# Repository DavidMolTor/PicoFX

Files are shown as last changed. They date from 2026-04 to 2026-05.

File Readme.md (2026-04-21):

# PICO FX

A simple stereo guitar effects platform using an RP Pico 2 development board.

## Introduction

This module is designed to be used as a development platform for guitar effects running on the RP2350 architecture.

The module contains a CS4272 codec with stereo inputs and outputs. It also includes a set of clean buffers to match the guitar and other effects in the chain.

All the power regulation is done through LDO regulators that prioritize low ripple in exchange for worse efficiency.

It is designed to work with 9V intput voltage. It also has a set of headers for it to be able to interface with a control board in the future.

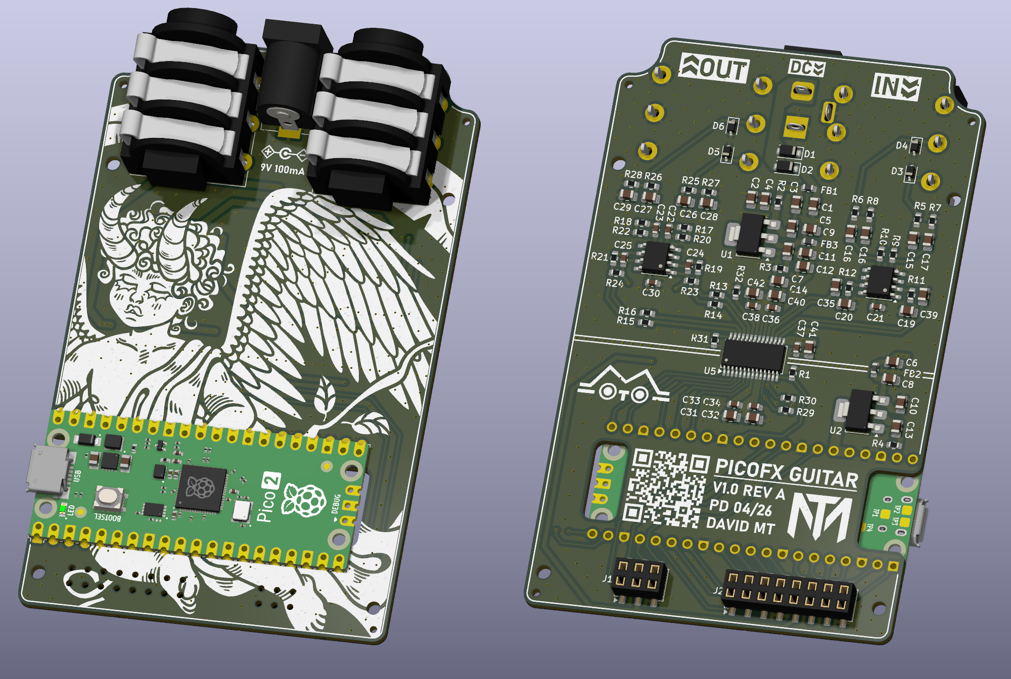
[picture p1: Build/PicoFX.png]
PICO FX


## Features

 - Clear separation between digital and analog sections.

 - Steareo input and output.

 - Clean voltage delivery.

 - Flexible interface for controls.

 - Easy future development.

 - Afforable BOM.

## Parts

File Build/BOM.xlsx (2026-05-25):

Reference | Qty | Value | Manufacturer Part | JLCPCB Part
C1,C2,C3,C4,C5,C6,C7,C8,C9,C10,C11,C12,C13,C14,C17,C18,C26,C27,C42 | 19 | 10u | CL21A106KAYNNNE | C15850
C15,C16,C19,C20,C28,C29,C35,C39 | 8 | 2.2n | CL21C222JBFNNNE | C28260
C21,C30,C33,C34,C36,C37,C38 | 7 | 100n | CC0603KRX7R9BB104 | C14663
C22,C23,C24,C25 | 4 | 330p | CL10C331JB8NNNC | C1664
C31,C32,C40,C41 | 4 | 1u | CL21B105KBFNNNE | C28323
D1 | 1 | SMF10CA | SMF10CA | C19077505
D2 | 1 | DSK24 | DSK24 | C22466352
D3,D4,D5,D6 | 4 | H15VSD3B | H15VSD3B | C20615814
FB1,FB2,FB3 | 3 | 850 | SDCL1608C68NJTDF | C13415
R1,R27,R28,R31,R32 | 5 | 47K | 0603WAF4702T5E | C25819
R2,R5,R6,R25,R26 | 5 | 100 | 0603WAF1000T5E | C22775
R3,R4 | 2 | 1 | 0603WAF100KT5E | C22936
R7,R8,R9,R10 | 4 | 1M | 0603WAF1004T5E | C22935
R11,R12 | 2 | 1K | 0603WAF1001T5E | C21190
R13,R14,R15,R16 | 4 | 15K | 0603WAF1502T5E | C22809
R17,R18,R23,R24 | 4 | 11K | 0603WAF1102T5E | C25950
R19,R20,R21,R22 | 4 | 820 | 0603WAF8200T5E | C23253
R29,R30 | 2 | 2.2K | 0603WAF2201T5E | C4190
U1 | 1 | AMS1117-5.0 | AMS1117-5.0 | C6187
U2 | 1 | AMS1117-3.3 | AMS1117-3.3 | C6186
U3,U4 | 2 | MCP6002-xSN | MCP6002T-I/SN | C7377
U5 | 1 | CS4272 | CS4272-CZZR | C2151111

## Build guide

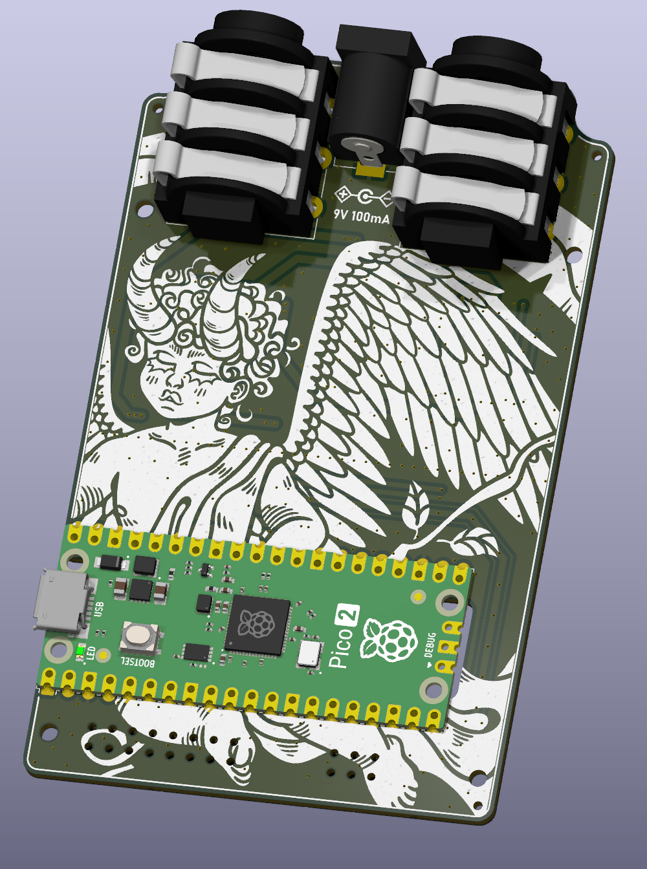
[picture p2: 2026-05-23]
Build/Front.png

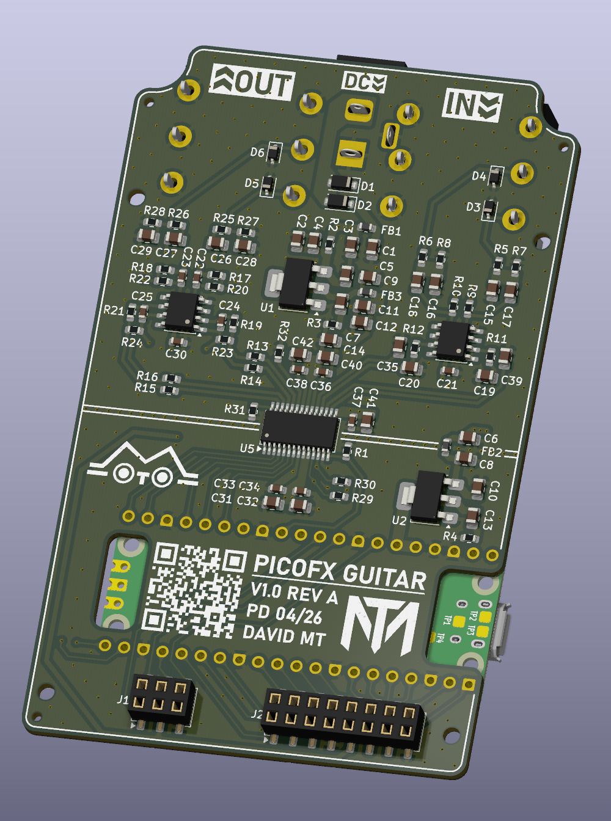
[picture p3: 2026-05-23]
Build/Back.png

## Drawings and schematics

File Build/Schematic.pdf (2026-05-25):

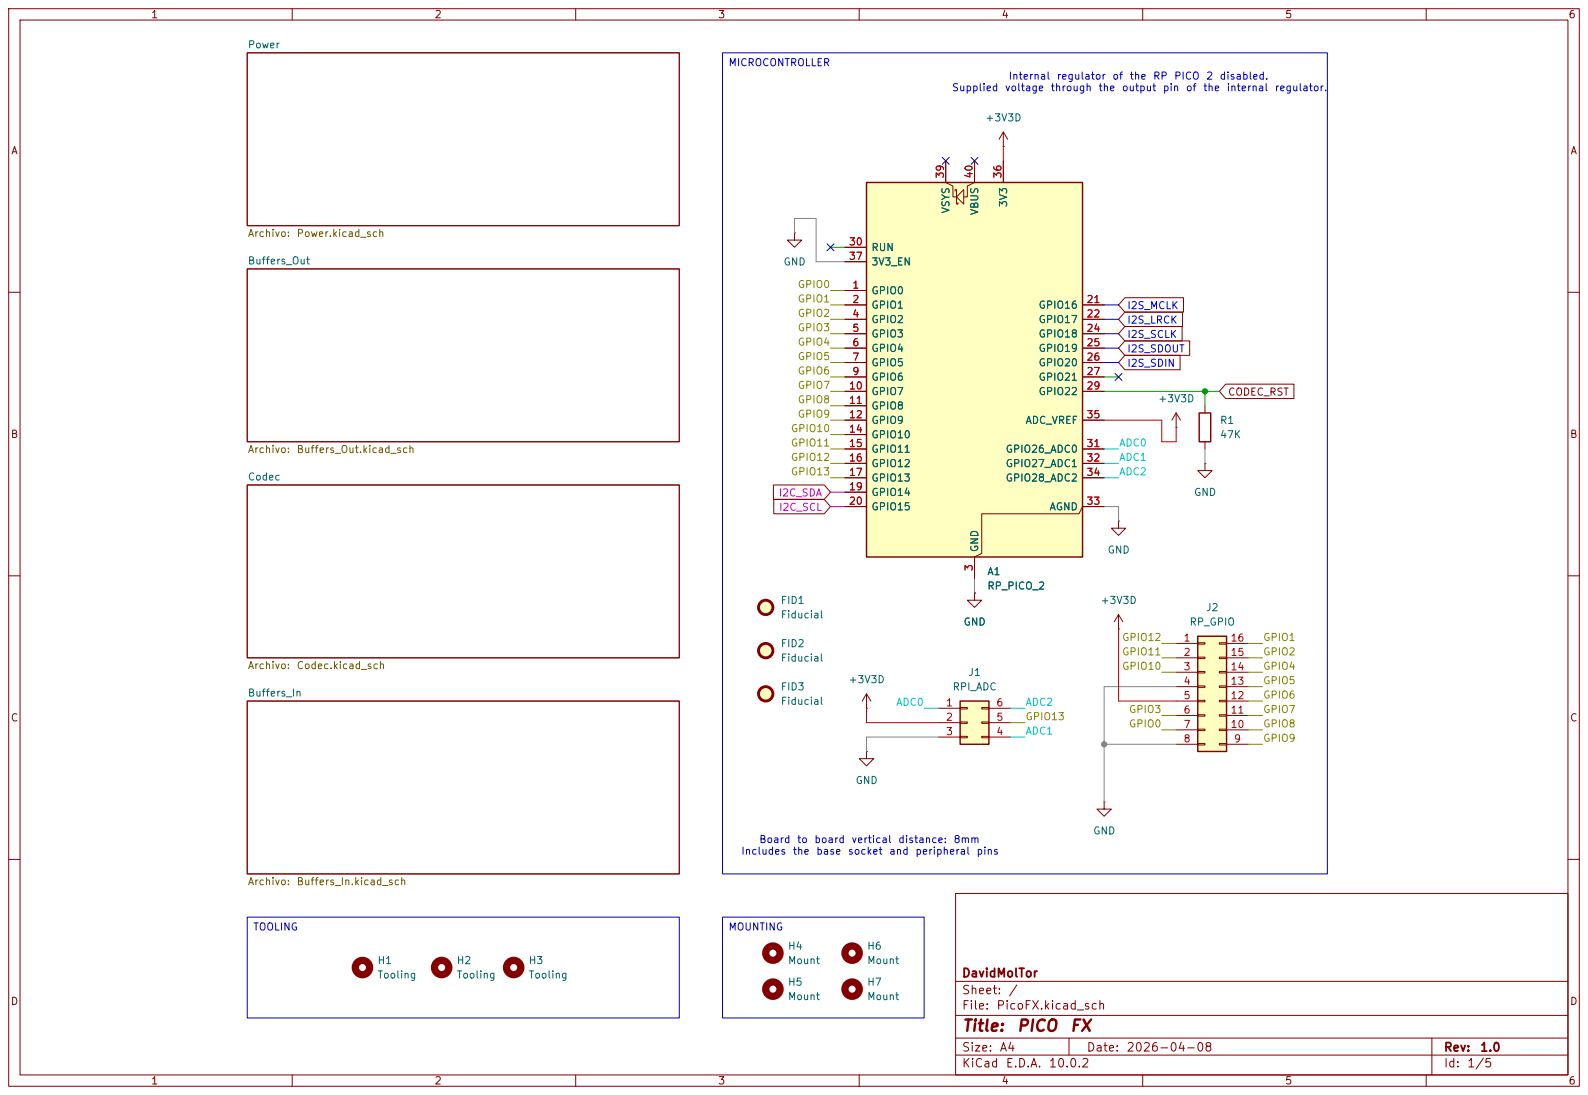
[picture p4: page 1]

Internal regulator of the RP PICO 2 disabled. Supplied voltage through the output pin of the internal regulator.

Board to board vertical distance: 8mm

Size: A4 | Rev: 1.0
KiCad E.D.A. 10.0.2 | Id: 1/5

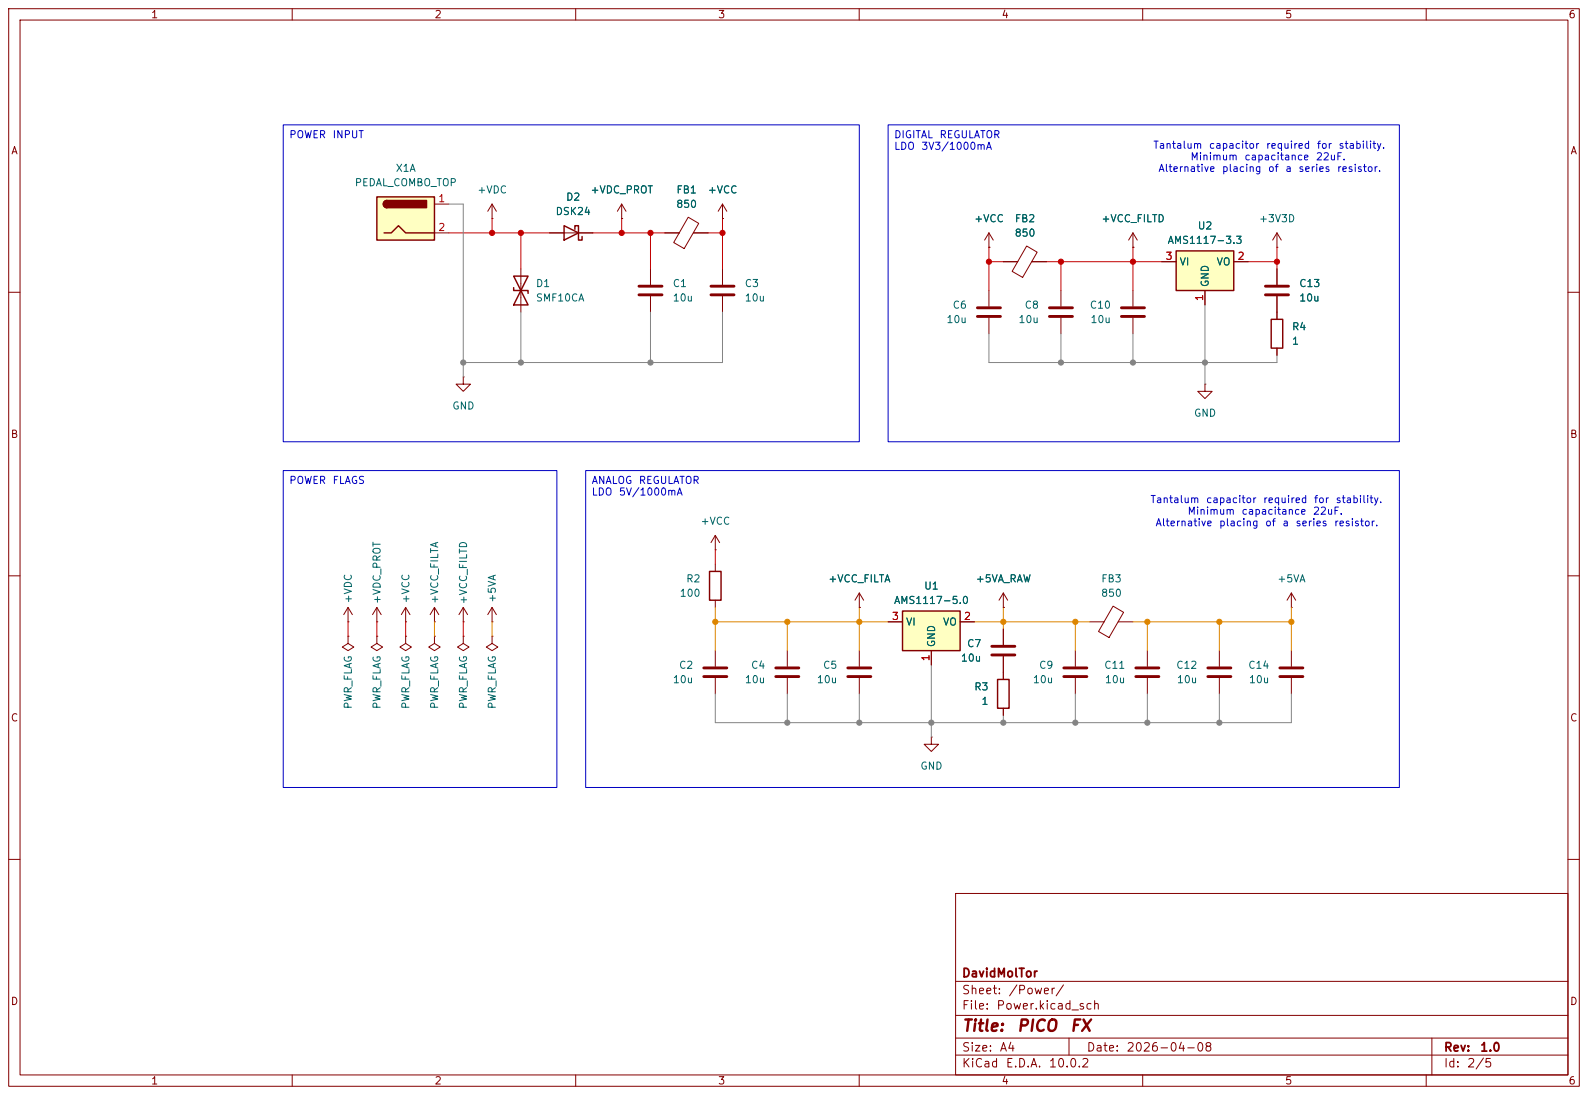
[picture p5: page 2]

Tantalum capacitor required for stability. Minimum capacitance 22uF. Alternative placing of a series resistor. Tantalum capacitor required for stability. Minimum capacitance 22uF. Alternative placing of a series resistor. +VCC FB2

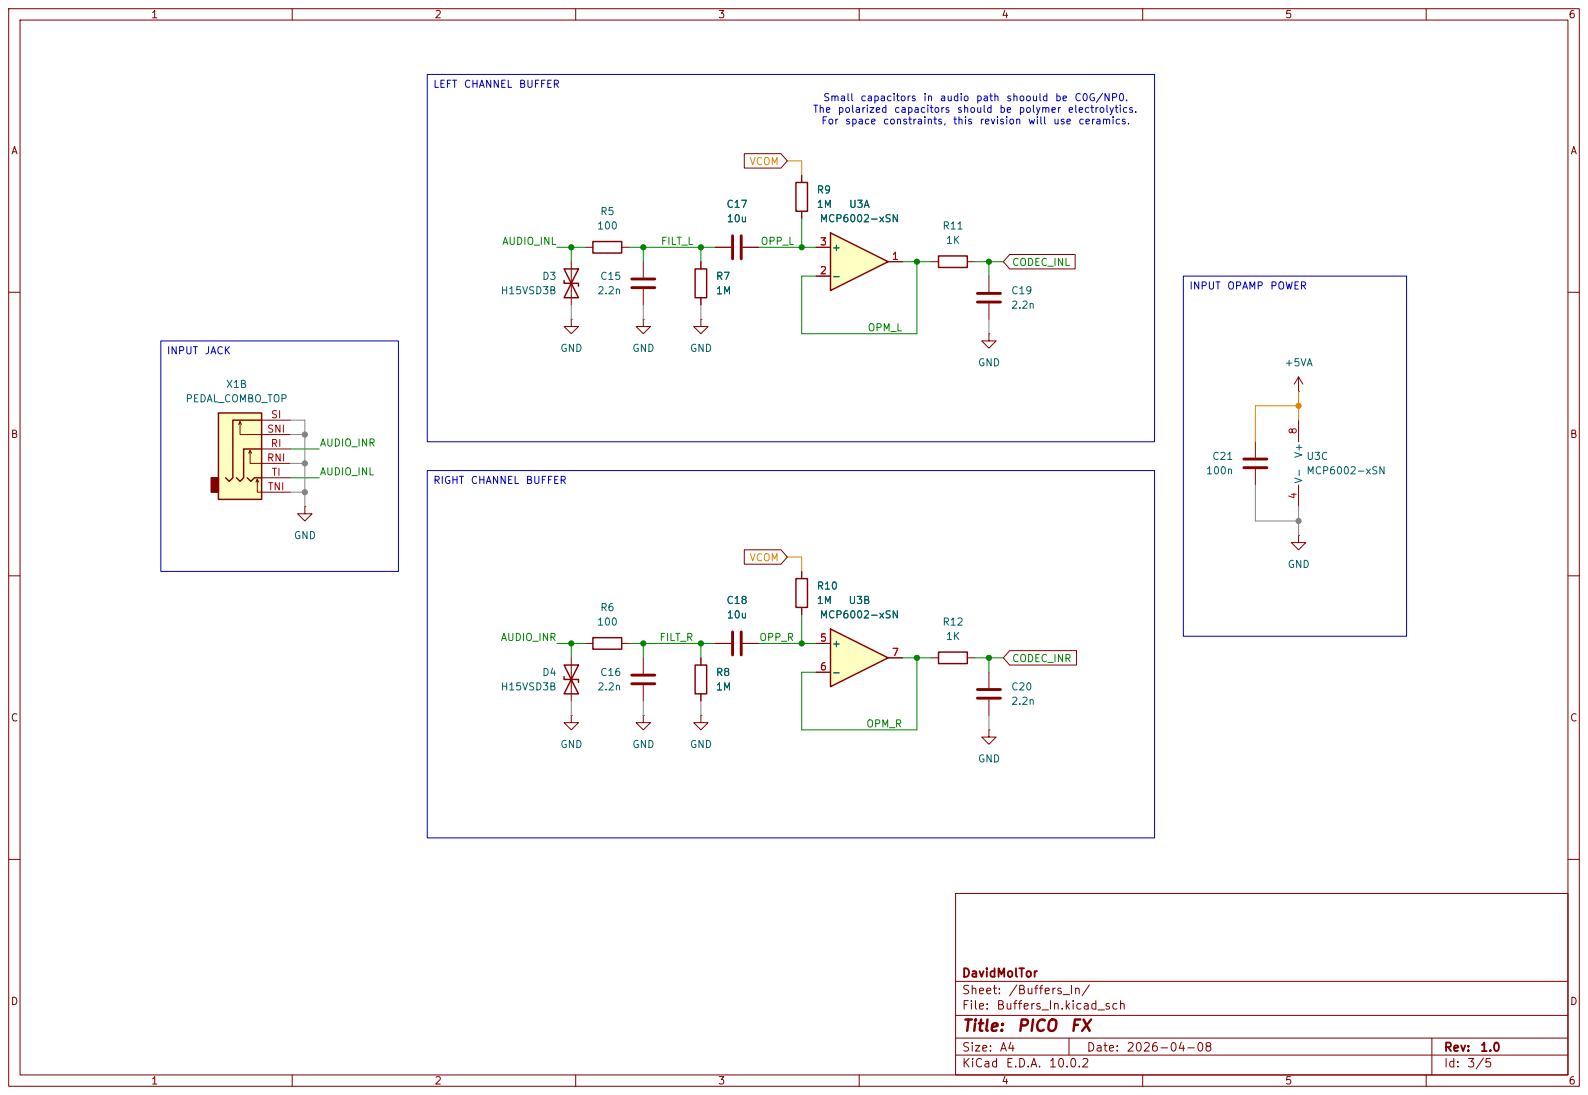
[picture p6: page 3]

Small capacitors in audio path shoould be C0G/NP0. The polarized capacitors should be polymer electrolytics. For space constraints, this revision will use ceramics. U3A MCP6002-xSN

RI RNI SI SNI TI TNI X1B

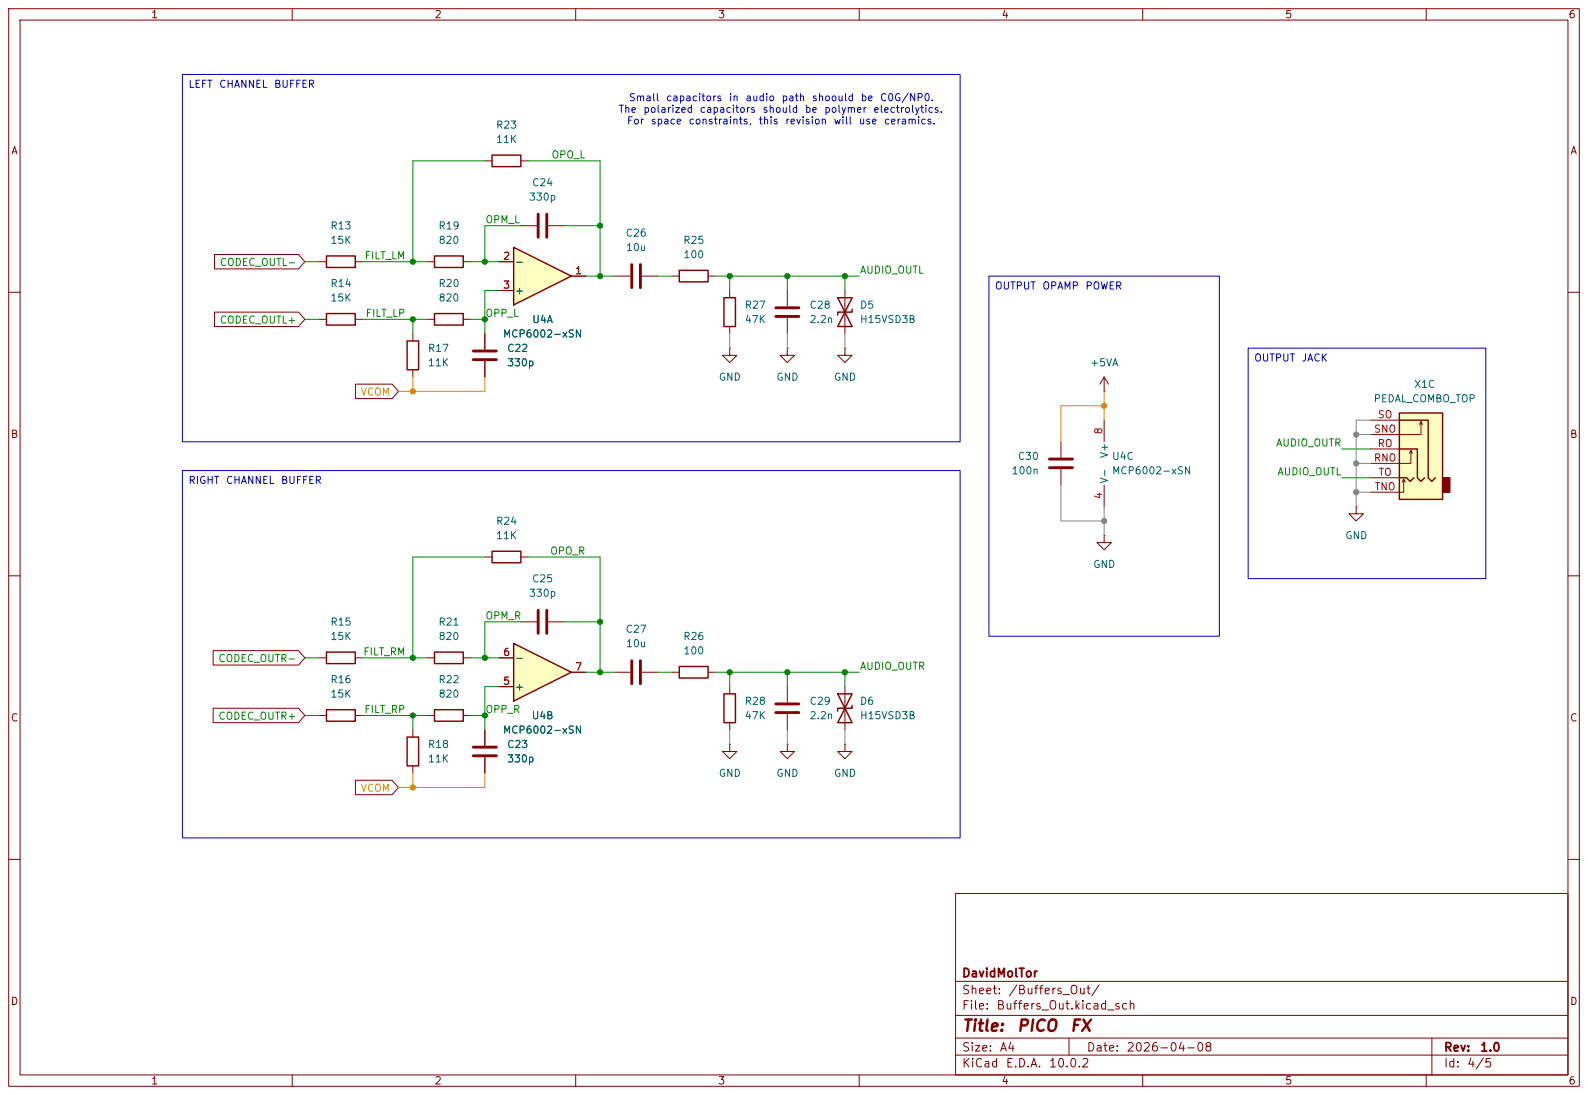
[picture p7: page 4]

Small capacitors in audio path shoould be C0G/NP0. The polarized capacitors should be polymer electrolytics. For space constraints, this revision will use ceramics. C22

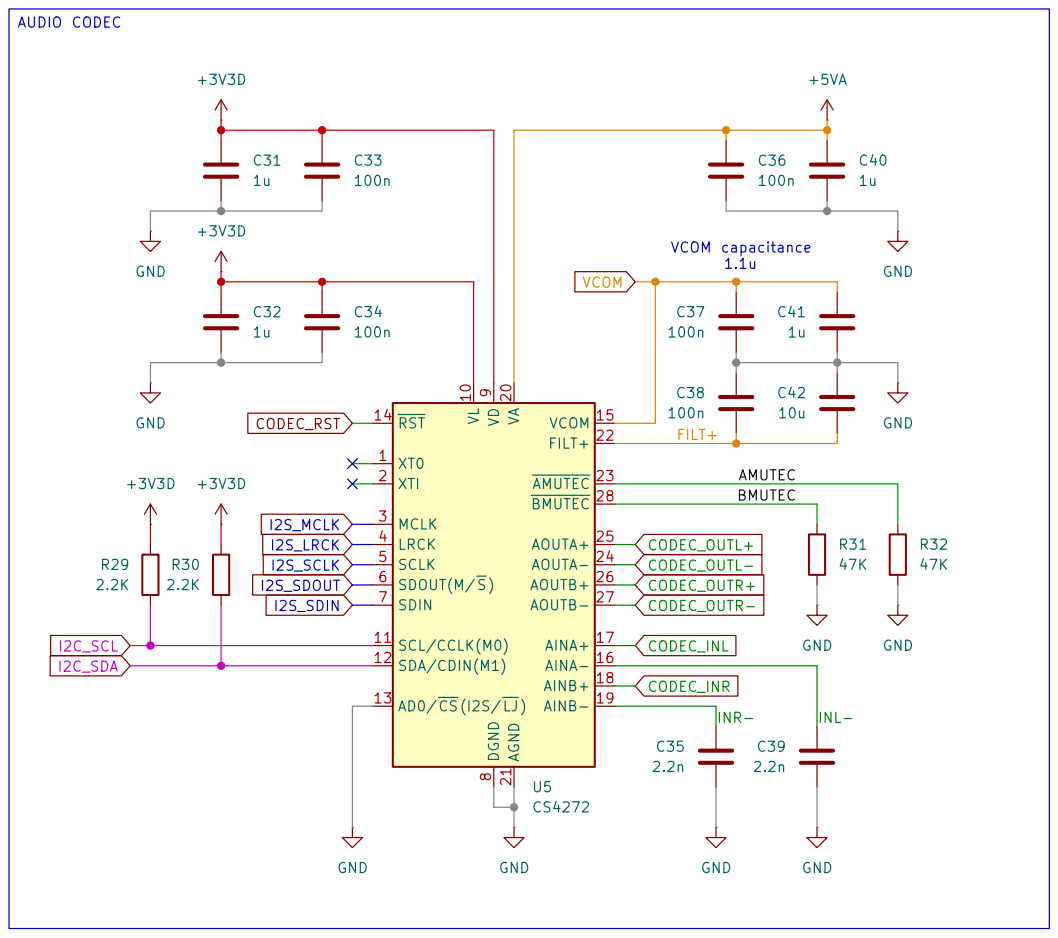
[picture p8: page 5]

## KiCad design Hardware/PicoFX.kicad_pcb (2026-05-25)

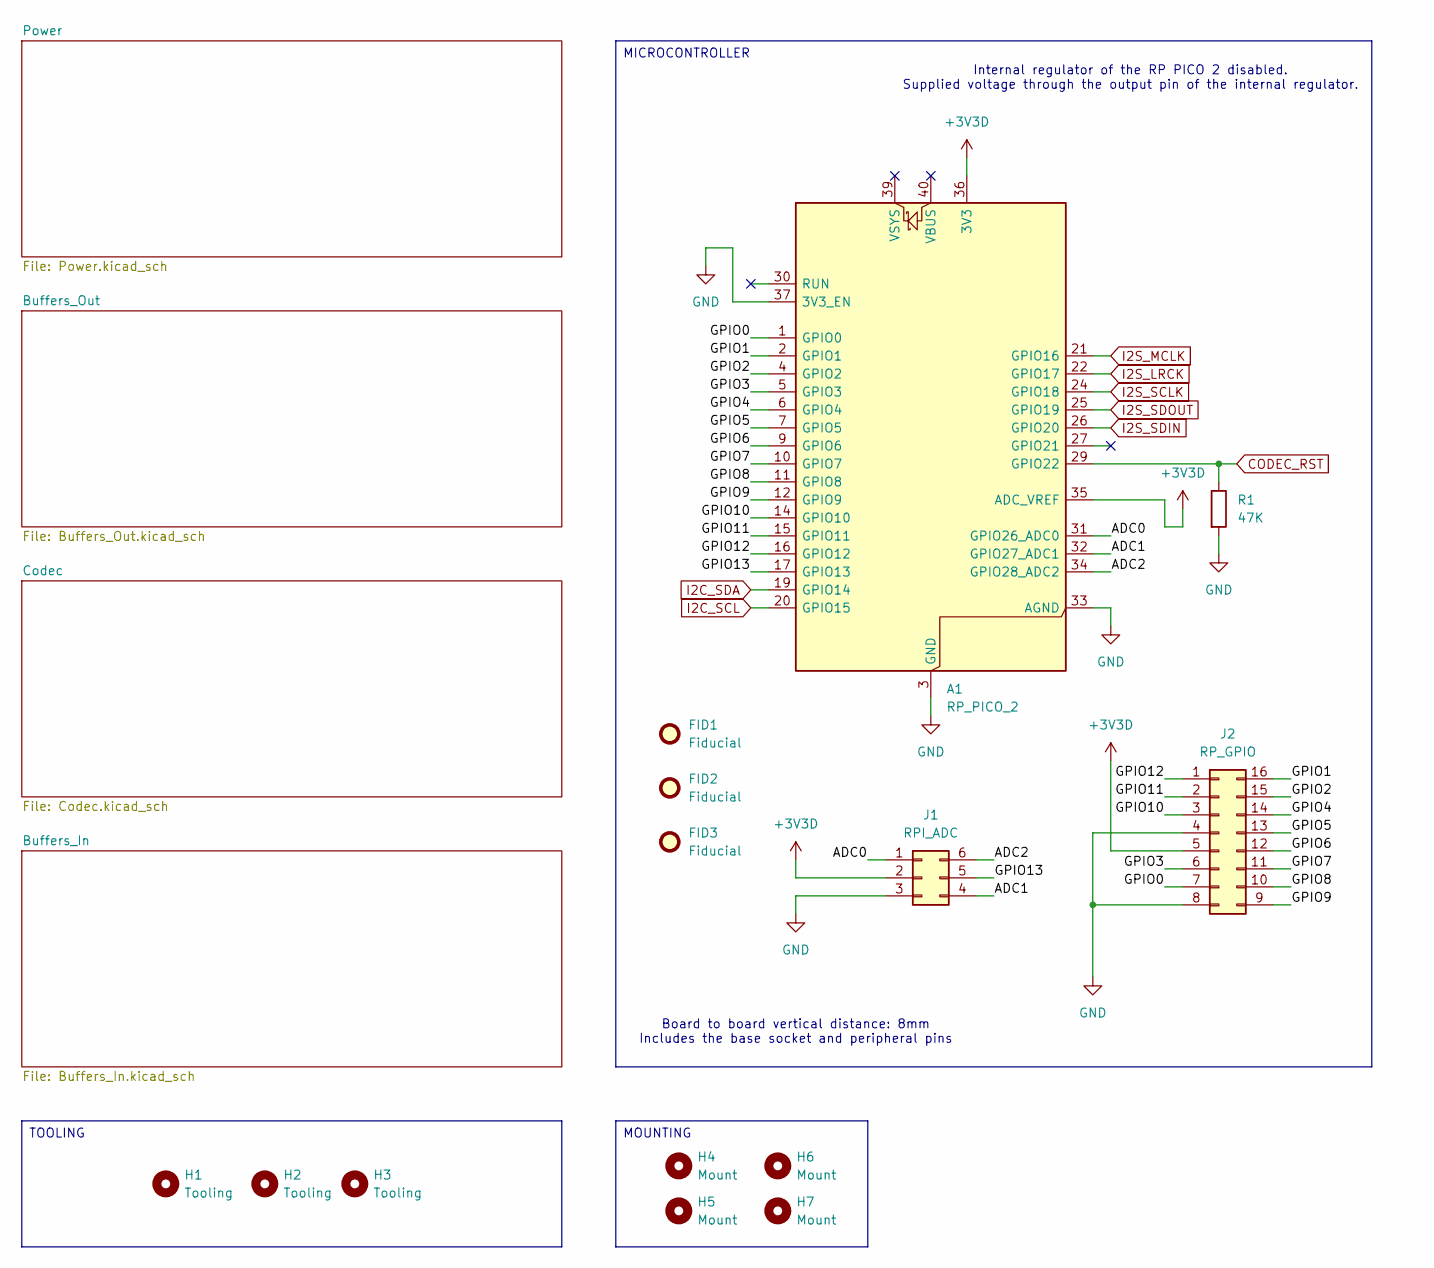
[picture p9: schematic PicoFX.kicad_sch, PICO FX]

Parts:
A1: RP_PICO_2; RP_PICO_2_SMD; Manufacturer Part Pico 2; JLCPCB Part C41407547
FID1, FID2, FID3: Fiducial; Fiducial_0.75mm_Mask1.5mm
H1, H2, H3: Tooling; ToolingHole_1.152mm
H4, H5, H6, H7: Mount; MountingHole_2.2mm_M2
J1: RPI_ADC; HEADER_THROUGH_2x03_P2.54mm; Manufacturer Part HC-PM254-5.0H-2x3PS-02A; JLCPCB Part C42163131
J2: RP_GPIO; HEADER_THROUGH_2x08_P2.54mm; Manufacturer Part HC-PM254-5.0H-2x8PS; JLCPCB Part C42163136
R1: 47K; R_0603_1608Metric; Manufacturer Part 0603WAF4702T5E; JLCPCB Part C25819

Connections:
+3V3D: A1.35 (ADC_VREF), A1.36 (3V3), J1.2, J2.5; also elsewhere on the board
/ADC0: A1.31 (GPIO26_ADC0), J1.1
/ADC1: A1.32 (GPIO27_ADC1), J1.4
/ADC2: A1.34 (GPIO28_ADC2), J1.6
/GPIO0: A1.1 (GPIO0), J2.7
/GPIO1: A1.2 (GPIO1), J2.16
/GPIO2: A1.4 (GPIO2), J2.15
/GPIO3: A1.5 (GPIO3), J2.6
/GPIO4: A1.6 (GPIO4), J2.14
/GPIO5: A1.7 (GPIO5), J2.13
/GPIO6: A1.9 (GPIO6), J2.12
/GPIO7: A1.10 (GPIO7), J2.11
/GPIO8: A1.11 (GPIO8), J2.10
/GPIO9: A1.12 (GPIO9), J2.9
/GPIO10: A1.14 (GPIO10), J2.3
/GPIO11: A1.15 (GPIO11), J2.2
/GPIO12: A1.16 (GPIO12), J2.1
/GPIO13: A1.17 (GPIO13), J1.5
CODEC_RST: A1.29 (GPIO22), R1.1; also elsewhere on the board
GND: A1.3 (GND), A1.8 (GND), A1.13 (GND), A1.18 (GND), A1.23 (GND), A1.28 (GND), A1.33 (AGND), A1.37 (3V3_EN), A1.38 (GND), J1.3, J2.4, J2.8, R1.2; also elsewhere on the board
I2C_SCL: A1.20 (GPIO15); also elsewhere on the board
I2C_SDA: A1.19 (GPIO14); also elsewhere on the board
I2S_LRCK: A1.22 (GPIO17); also elsewhere on the board
I2S_MCLK: A1.21 (GPIO16); also elsewhere on the board
I2S_SCLK: A1.24 (GPIO18); also elsewhere on the board
I2S_SDIN: A1.26 (GPIO20); also elsewhere on the board
I2S_SDOUT: A1.25 (GPIO19); also elsewhere on the board

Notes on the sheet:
Board to board vertical distance: 8mm Includes the base socket and peripheral pins
Internal regulator of the RP PICO 2 disabled. Supplied voltage through the output pin of the internal regulator.
MICROCONTROLLER
TOOLING
MOUNTING

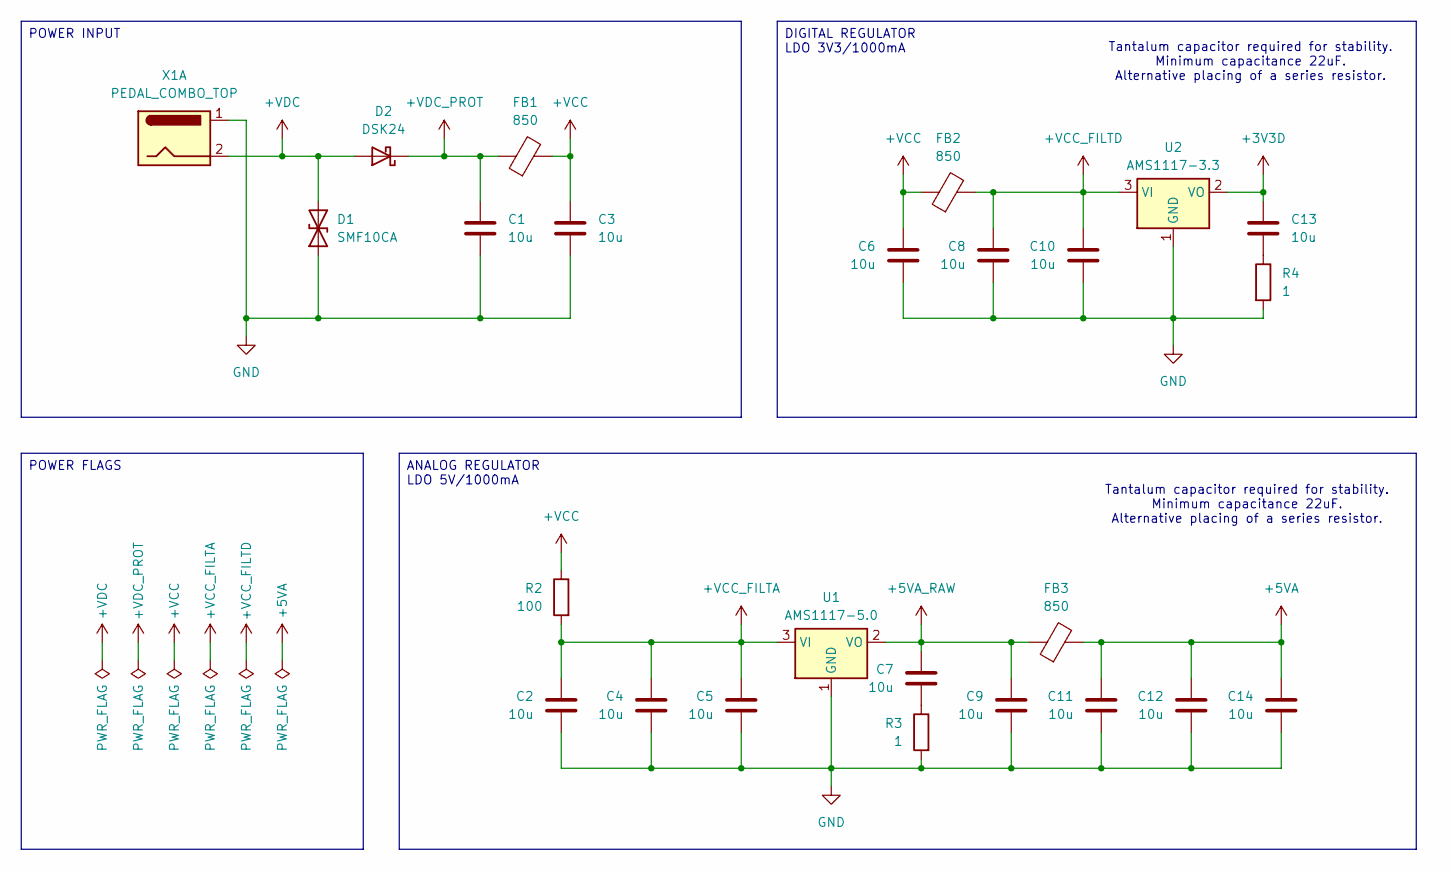
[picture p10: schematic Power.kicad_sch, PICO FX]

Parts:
C1, C2, C3, C4, C5, C6, C7, C8, C9, C10, C11, C12, C13, C14: 10u; C_0805_2012Metric; Manufacturer Part CL21A106KAYNNNE; JLCPCB Part C15850
D1: SMF10CA; D_SOD-123F; Manufacturer Part SMF10CA; JLCPCB Part C19077505
D2: DSK24; D_SOD-123F; Manufacturer Part DSK24; JLCPCB Part C22466352
FB1, FB2, FB3: 850; L_0603_1608Metric; Manufacturer Part SDCL1608C68NJTDF; JLCPCB Part C13415
R2: 100; R_0603_1608Metric; Manufacturer Part 0603WAF1000T5E; JLCPCB Part C22775
R3, R4: 1; R_0603_1608Metric; Manufacturer Part 0603WAF100KT5E; JLCPCB Part C22936
U1: AMS1117-5.0; SOT-223-3_TabPin2; Manufacturer Part AMS1117-5.0; JLCPCB Part C6187
U2: AMS1117-3.3; SOT-223-3_TabPin2; Manufacturer Part AMS1117-3.3; JLCPCB Part C6186
X1: PEDAL_COMBO_TOP

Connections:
+3V3D: C13.1, U2.2 (VO); also elsewhere on the board
+5VA: C11.1, C12.1, C14.1, FB3.2; also elsewhere on the board
+5VA_RAW: C7.1, C9.1, FB3.1, U1.2 (VO)
+VCC: C3.1, C6.1, FB1.2, FB2.1, R2.1
+VCC_FILTA: C2.1, C4.1, C5.1, R2.2, U1.3 (VI)
+VCC_FILTD: C8.1, C10.1, FB2.2, U2.3 (VI)
+VDC: D1.2 (A2), D2.2 (A), X1.2
+VDC_PROT: C1.1, D2.1 (K), FB1.1
GND: C1.2, C2.2, C3.2, C4.2, C5.2, C6.2, C8.2, C9.2, C10.2, C11.2, C12.2, C14.2, D1.1 (A1), R3.2, R4.2, U1.1 (GND), U2.1 (GND), X1.1; also elsewhere on the board
unnamed: C7.2, R3.1
unnamed: C13.2, R4.1

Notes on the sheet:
Tantalum capacitor required for stability. Minimum capacitance 22uF. Alternative placing of a series resistor.
DIGITAL REGULATOR LDO 3V3/1000mA
POWER INPUT
ANALOG REGULATOR LDO 5V/1000mA
POWER FLAGS

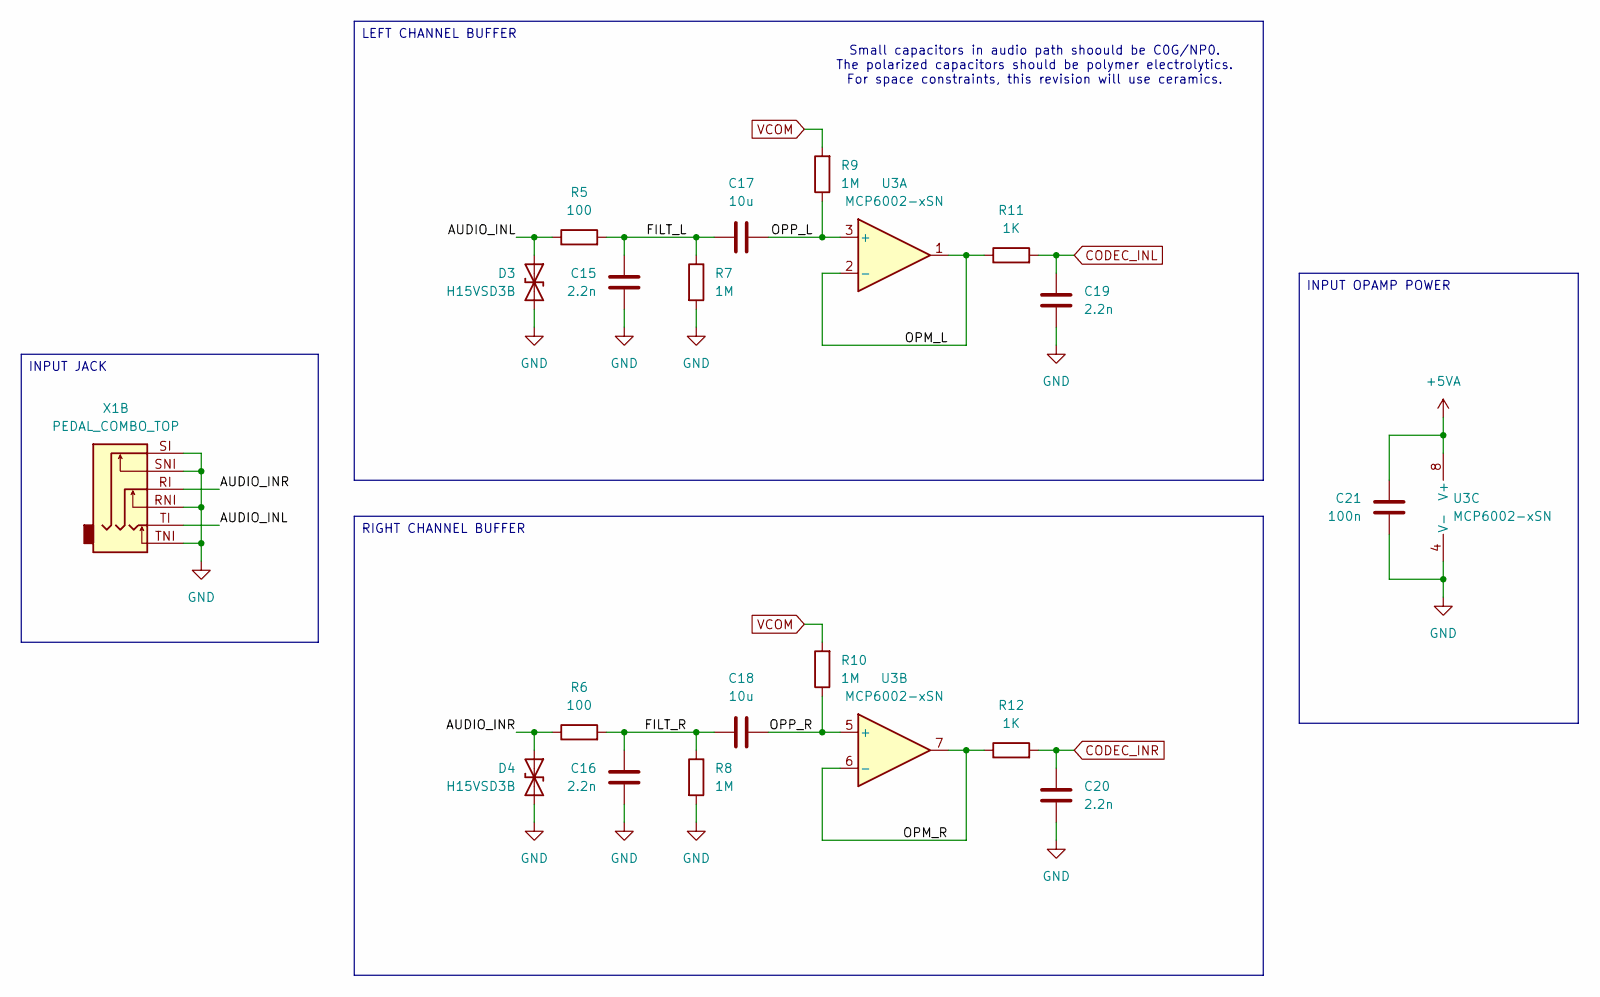
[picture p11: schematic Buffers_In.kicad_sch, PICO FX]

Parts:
C15, C16, C19, C20: 2.2n; C_0805_2012Metric; Manufacturer Part CL21C222JBFNNNE; JLCPCB Part C28260
C17, C18: 10u; C_0805_2012Metric; Manufacturer Part CL21A106KAYNNNE; JLCPCB Part C15850
C21: 100n; C_0603_1608Metric; Manufacturer Part CC0603KRX7R9BB104; JLCPCB Part C14663
D3, D4: H15VSD3B; D_SOD-323; Manufacturer Part H15VSD3B; JLCPCB Part C20615814
R5, R6: 100; R_0603_1608Metric; Manufacturer Part 0603WAF1000T5E; JLCPCB Part C22775
R7, R8, R9, R10: 1M; R_0603_1608Metric; Manufacturer Part 0603WAF1004T5E; JLCPCB Part C22935
R11, R12: 1K; R_0603_1608Metric; Manufacturer Part 0603WAF1001T5E; JLCPCB Part C21190
U3: MCP6002-xSN; SOIC-8_3.9x4.9mm_P1.27mm; Manufacturer Part MCP6002T-I/SN; JLCPCB Part C7377
X1: PEDAL_COMBO_TOP

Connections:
+5VA: C21.1, U3.8 (V+); also elsewhere on the board
/Buffers_In/AUDIO_INL: D3.1 (A1), R5.1, X1.TI
/Buffers_In/AUDIO_INR: D4.1 (A1), R6.1, X1.RI
/Buffers_In/FILT_L: C15.2, C17.1, R5.2, R7.1
/Buffers_In/FILT_R: C16.2, C18.1, R6.2, R8.1
/Buffers_In/OPM_L: R11.1, U3.1, U3.2 (-)
/Buffers_In/OPM_R: R12.1, U3.6 (-), U3.7
/Buffers_In/OPP_L: C17.2, R9.1, U3.3 (+)
/Buffers_In/OPP_R: C18.2, R10.1, U3.5 (+)
CODEC_INL: C19.1, R11.2; also elsewhere on the board
CODEC_INR: C20.1, R12.2; also elsewhere on the board
GND: C15.1, C16.1, C19.2, C20.2, C21.2, D3.2 (A2), D4.2 (A2), R7.2, R8.2, U3.4 (V-), X1.RNI, X1.SI, X1.SNI, X1.TNI; also elsewhere on the board
VCOM: R9.2, R10.2; also elsewhere on the board

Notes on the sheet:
Small capacitors in audio path shoould be C0G/NP0. The polarized capacitors should be polymer electrolytics. For space constraints, this revision will use ceramics.
LEFT CHANNEL BUFFER
INPUT OPAMP POWER
INPUT JACK
RIGHT CHANNEL BUFFER

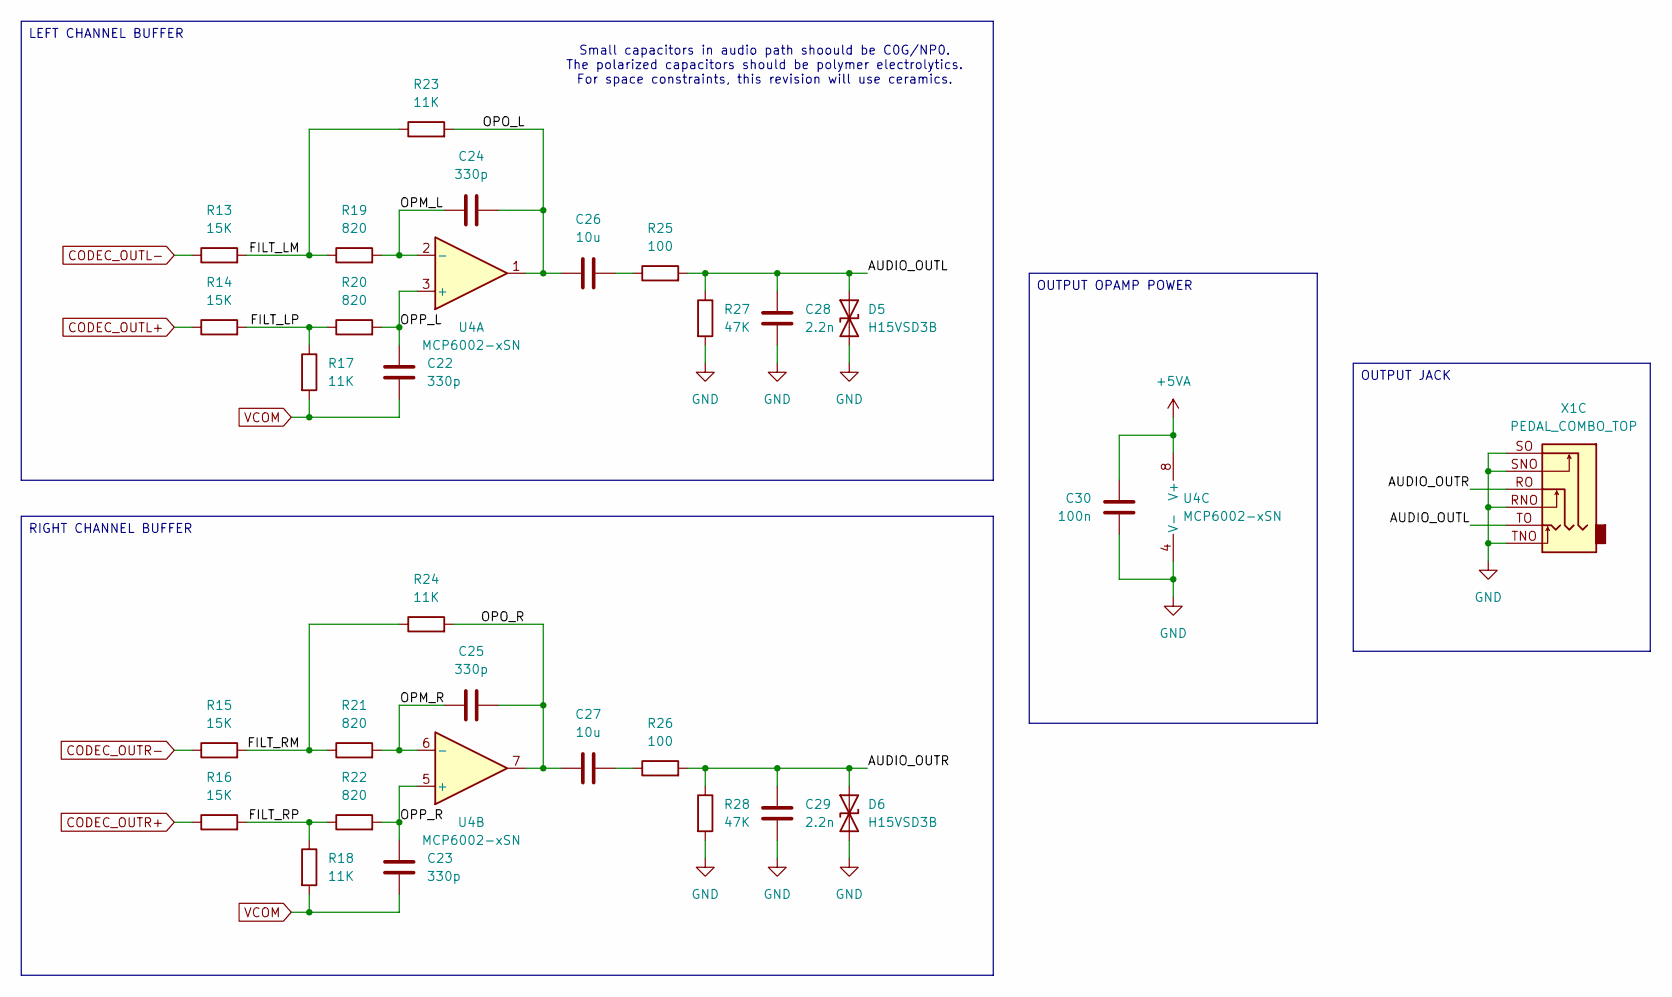
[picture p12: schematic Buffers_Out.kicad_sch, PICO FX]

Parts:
C22, C23, C24, C25: 330p; C_0603_1608Metric; Manufacturer Part CL10C331JB8NNNC; JLCPCB Part C1664
C26, C27: 10u; C_0805_2012Metric; Manufacturer Part CL21A106KAYNNNE; JLCPCB Part C15850
C28, C29: 2.2n; C_0805_2012Metric; Manufacturer Part CL21C222JBFNNNE; JLCPCB Part C28260
C30: 100n; C_0603_1608Metric; Manufacturer Part CC0603KRX7R9BB104; JLCPCB Part C14663
D5, D6: H15VSD3B; D_SOD-323; Manufacturer Part H15VSD3B; JLCPCB Part C20615814
R13, R14, R15, R16: 15K; R_0603_1608Metric; Manufacturer Part 0603WAF1502T5E; JLCPCB Part C22809
R17, R18, R23, R24: 11K; R_0603_1608Metric; Manufacturer Part 0603WAF1102T5E; JLCPCB Part C25950
R19, R20, R21, R22: 820; R_0603_1608Metric; Manufacturer Part 0603WAF8200T5E; JLCPCB Part C23253
R25, R26: 100; R_0603_1608Metric; Manufacturer Part 0603WAF1000T5E; JLCPCB Part C22775
R27, R28: 47K; R_0603_1608Metric; Manufacturer Part 0603WAF4702T5E; JLCPCB Part C25819
U4: MCP6002-xSN; SOIC-8_3.9x4.9mm_P1.27mm; Manufacturer Part MCP6002T-I/SN; JLCPCB Part C7377
X1: PEDAL_COMBO_TOP

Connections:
+5VA: C30.1, U4.8 (V+); also elsewhere on the board
/Buffers_Out/AUDIO_OUTL: C28.1, D5.1 (A1), R25.2, R27.1, X1.TO
/Buffers_Out/AUDIO_OUTR: C29.1, D6.1 (A1), R26.2, R28.1, X1.RO
/Buffers_Out/FILT_LM: R13.2, R19.1, R23.1
/Buffers_Out/FILT_LP: R14.2, R17.1, R20.1
/Buffers_Out/FILT_RM: R15.2, R21.1, R24.1
/Buffers_Out/FILT_RP: R16.2, R18.1, R22.1
/Buffers_Out/OPM_L: C24.1, R19.2, U4.2 (-)
/Buffers_Out/OPM_R: C25.1, R21.2, U4.6 (-)
/Buffers_Out/OPO_L: C24.2, C26.1, R23.2, U4.1
/Buffers_Out/OPO_R: C25.2, C27.1, R24.2, U4.7
/Buffers_Out/OPP_L: C22.1, R20.2, U4.3 (+)
/Buffers_Out/OPP_R: C23.1, R22.2, U4.5 (+)
CODEC_OUTL+: R14.1; also elsewhere on the board
CODEC_OUTL-: R13.1; also elsewhere on the board
CODEC_OUTR+: R16.1; also elsewhere on the board
CODEC_OUTR-: R15.1; also elsewhere on the board
GND: C28.2, C29.2, C30.2, D5.2 (A2), D6.2 (A2), R27.2, R28.2, U4.4 (V-), X1.RNO, X1.SNO, X1.SO, X1.TNO; also elsewhere on the board
unnamed: C26.2, R25.1
unnamed: C27.2, R26.1
VCOM: C22.2, C23.2, R17.2, R18.2; also elsewhere on the board

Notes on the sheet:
Small capacitors in audio path shoould be C0G/NP0. The polarized capacitors should be polymer electrolytics. For space constraints, this revision will use ceramics.
OUTPUT JACK
LEFT CHANNEL BUFFER
RIGHT CHANNEL BUFFER
OUTPUT OPAMP POWER

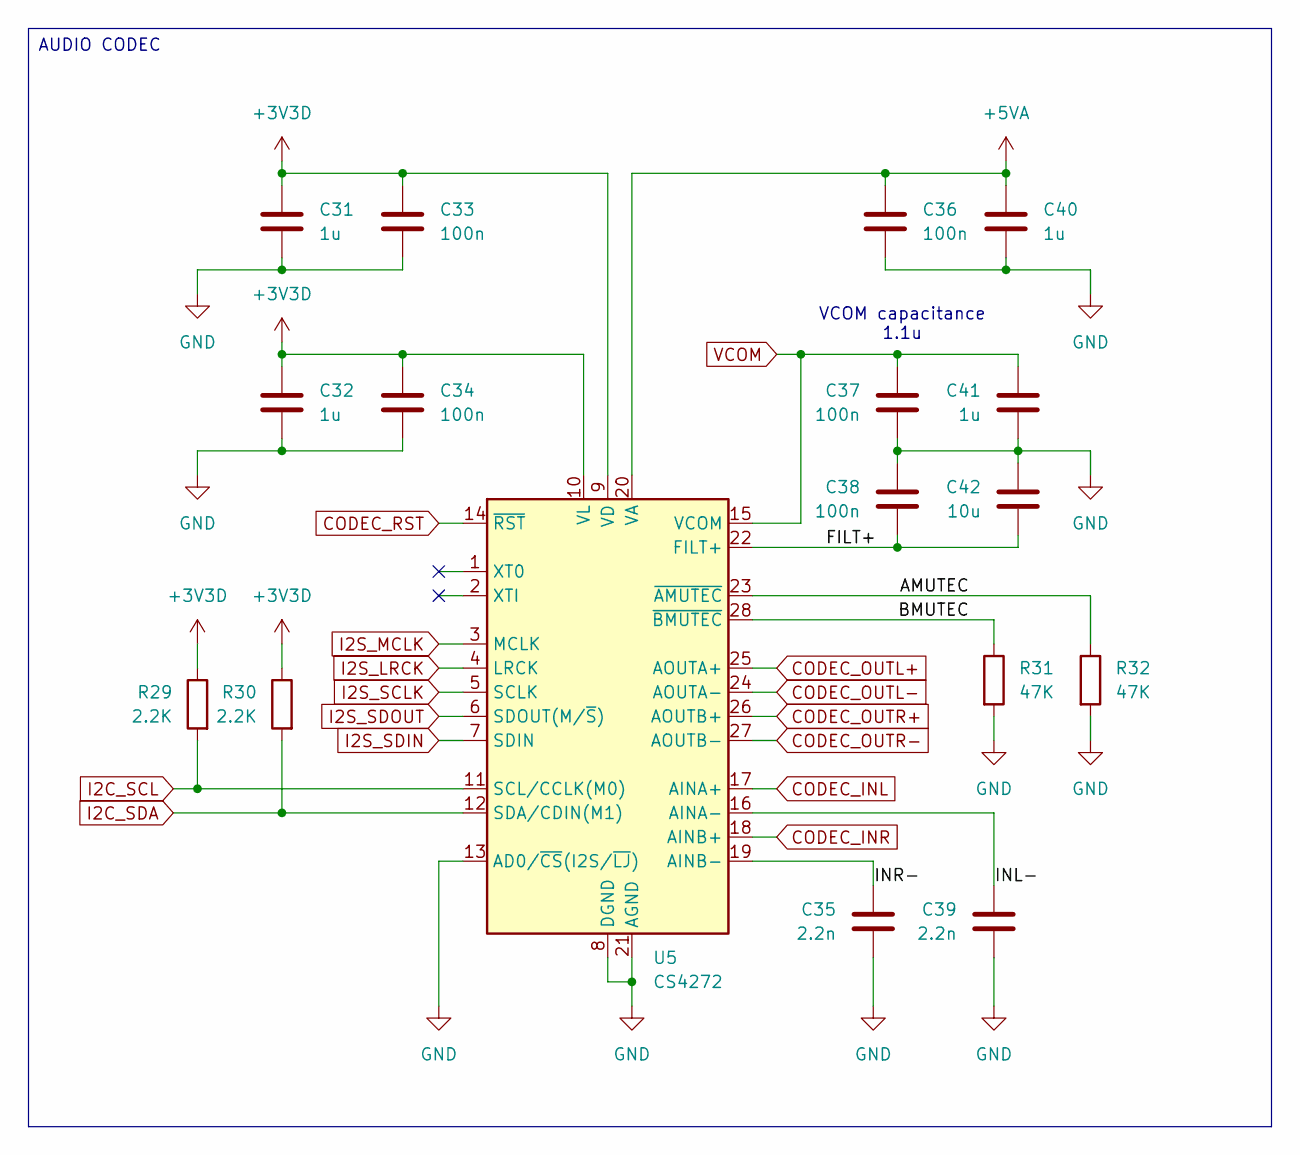
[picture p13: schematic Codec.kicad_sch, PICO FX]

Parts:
C31, C32, C40, C41: 1u; C_0805_2012Metric; Manufacturer Part CL21B105KBFNNNE; JLCPCB Part C28323
C33, C34, C36, C37, C38: 100n; C_0603_1608Metric; Manufacturer Part CC0603KRX7R9BB104; JLCPCB Part C14663
C35, C39: 2.2n; C_0805_2012Metric; Manufacturer Part CL21C222JBFNNNE; JLCPCB Part C28260
C42: 10u; C_0805_2012Metric; Manufacturer Part CL21A106KAYNNNE; JLCPCB Part C15850
R29, R30: 2.2K; R_0603_1608Metric; Manufacturer Part 0603WAF2201T5E; JLCPCB Part C4190
R31, R32: 47K; R_0603_1608Metric; Manufacturer Part 0603WAF4702T5E; JLCPCB Part C25819
U5: CS4272; TSSOP-28_4.4x9.7mm_P0.65mm; Manufacturer Part CS4272-CZZR; JLCPCB Part C2151111

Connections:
+3V3D: C31.2, C32.2, C33.1, C34.1, R29.1, R30.1, U5.9 (VD), U5.10 (VL); also elsewhere on the board
+5VA: C36.2, C40.1, U5.20 (VA); also elsewhere on the board
/Codec/AMUTEC: R32.1, U5.23 (~AMUTEC)
/Codec/BMUTEC: R31.1, U5.28 (~BMUTEC)
/Codec/FILT+: C38.1, C42.2, U5.22 (FILT+)
/Codec/INL-: C39.1, U5.16 (AINA-)
/Codec/INR-: C35.1, U5.19 (AINB-)
CODEC_INL: U5.17 (AINA+); also elsewhere on the board
CODEC_INR: U5.18 (AINB+); also elsewhere on the board
CODEC_OUTL+: U5.25 (AOUTA+); also elsewhere on the board
CODEC_OUTL-: U5.24 (AOUTA-); also elsewhere on the board
CODEC_OUTR+: U5.26 (AOUTB+); also elsewhere on the board
CODEC_OUTR-: U5.27 (AOUTB-); also elsewhere on the board
CODEC_RST: U5.14 (~RST); also elsewhere on the board
GND: C31.1, C32.1, C33.2, C34.2, C35.2, C36.1, C37.2, C38.2, C39.2, C40.2, C41.2, C42.1, R31.2, R32.2, U5.8 (DGND), U5.13 (AD0/~CS(I2S/~LJ)), U5.21 (AGND); also elsewhere on the board
I2C_SCL: R29.2, U5.11 (SCL/CCLK(M0)); also elsewhere on the board
I2C_SDA: R30.2, U5.12 (SDA/CDIN(M1)); also elsewhere on the board
I2S_LRCK: U5.4 (LRCK); also elsewhere on the board
I2S_MCLK: U5.3 (MCLK); also elsewhere on the board
I2S_SCLK: U5.5 (SCLK); also elsewhere on the board
I2S_SDIN: U5.7 (SDIN); also elsewhere on the board
I2S_SDOUT: U5.6 (SDOUT(M/~S)); also elsewhere on the board
VCOM: C37.1, C41.1, U5.15 (VCOM); also elsewhere on the board

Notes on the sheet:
VCOM capacitance 1.1u
AUDIO CODEC

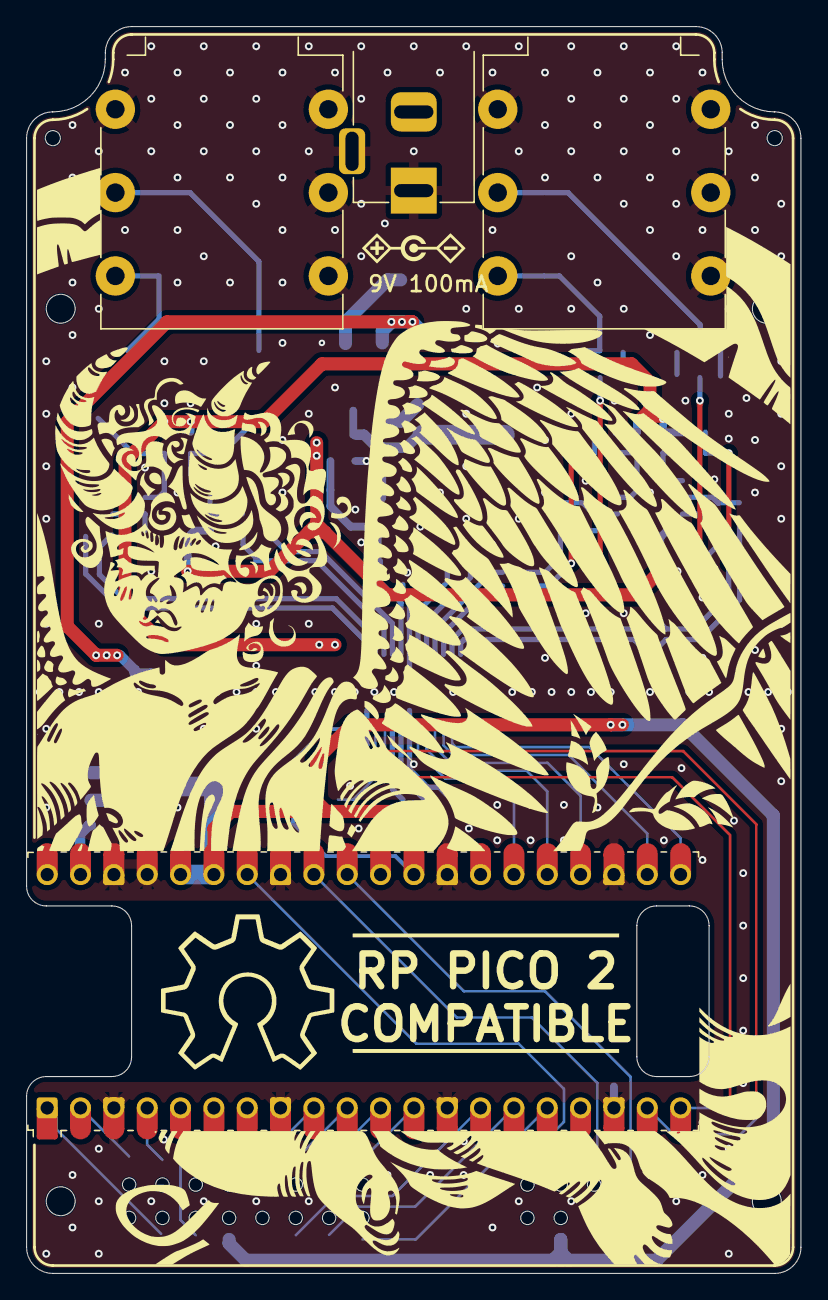
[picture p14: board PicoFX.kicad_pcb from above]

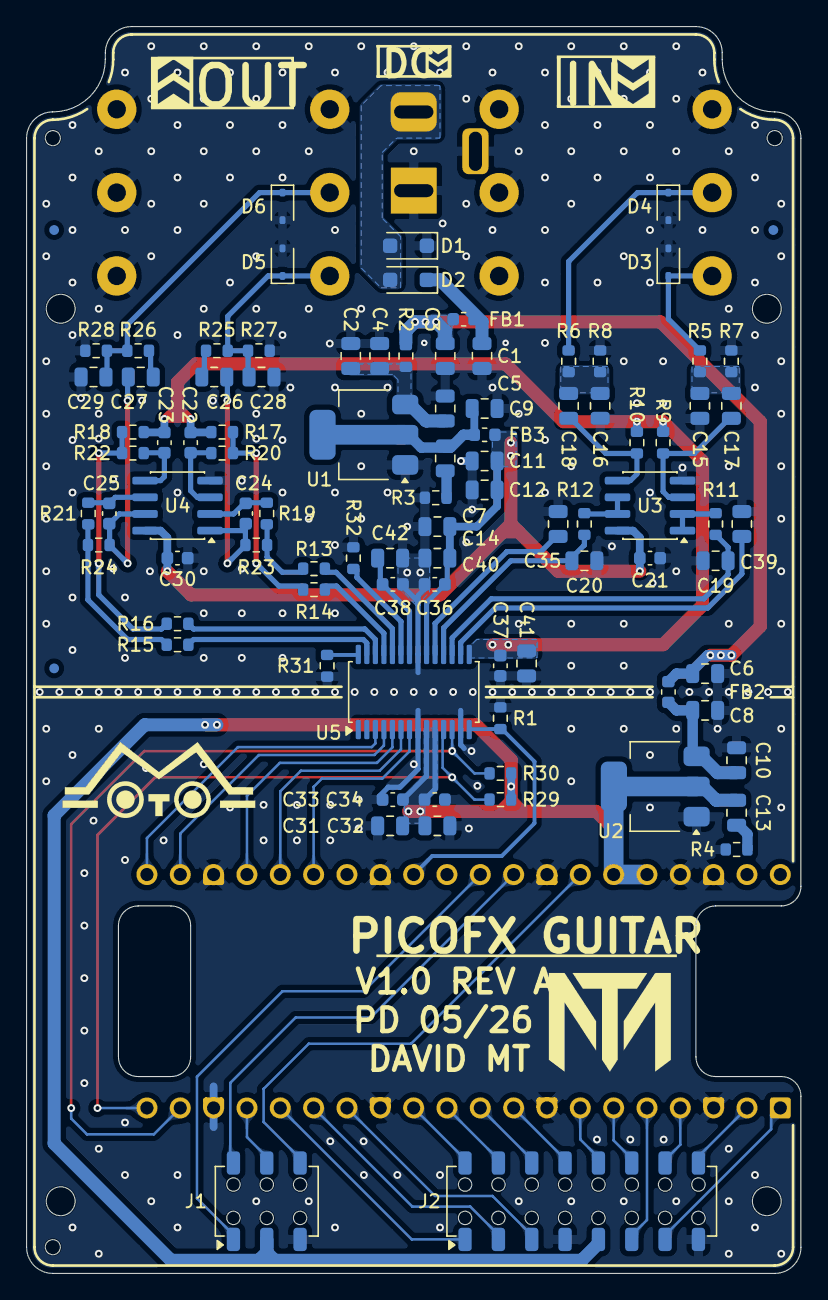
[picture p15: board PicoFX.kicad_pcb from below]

Board: 4 copper layers, 59.0 x 95.0 mm, 102 parts (97 on the bottom side), 70 nets.

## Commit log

2026-04-09 Initial strcture
    Added the initial project structure.
    Added the input buffer modules.
    Added the output buffer modules.
    [Buffers_In.kicad_sch, Buffers_Out.kicad_sch, Codec.kicad_sch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]
2026-04-13 Bias voltage fix
    Fixed the label for the output bias voltage.
    [Buffers_Out.kicad_sch]
2026-04-14 Buffer and layout
    Updated the input and output buffers.
    Updated the board layout.
    [Buffers_In.kicad_sch, Buffers_Out.kicad_sch, Codec.kicad_sch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]
2026-04-16 Layout and power supply filtering
    Updated the project to KiCad 10.0.
    Added additional power supply filtering.
    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
    [Buffers_In.kicad_sch, Buffers_Out.kicad_sch, Codec.kicad_sch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]
2026-04-17 Via stitching
    Added missing vias to GND.
    [SimpleCodec.kicad_pcb]
2026-04-21 Name update
    Updated the name of the project.
    Updated the silkscreen for the PCB layout.
    [BOM.xlsx, Buffers_In.kicad_sch, Buffers_Out.kicad_sch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]
2026-04-25 Layout points
    Removed unused points in layout.
    [PicoFX.kicad_pcb]
2026-04-26 Layout review
    Updated the LDO layout to include a series resistor for stability.
    Updated all build files.
    [BOM.xlsx, Buffers_In.kicad_sch, Buffers_Out.kicad_sch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]
2026-05-23 Output files
    Updated the board silkscreen.
    Upddated the output files.
    [Buffers_In.kicad_sch, Buffers_Out.kicad_sch, Codec.kicad_sch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]
2026-05-23 Minor adjustments
    Updated the output files.
    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
    [PicoFX.kicad_pcb]
2026-05-23 Output files
    Minor changes to the board and schematic.
    Added a 3D model of the complete board.
    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
    [PicoFX.kicad_pcb, PicoFX.kicad_sch]
2026-05-25 Assembly review
    Performed a full review of the schematic and layout.
    Minor changes to the schematic and layout.
    Updated output files.
    [BOM.xlsx, Buffers_In.kicad_sch, Buffers_Out.kicad_sch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]
